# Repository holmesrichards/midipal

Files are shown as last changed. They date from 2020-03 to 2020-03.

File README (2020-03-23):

Midipal, the MIDI swiss army knife.

A midi in, a midi out, a small display, an encoder ; 20 awesome features:

* MIDI monitor
* BPM counter
* Keyboard splitter
* Note dispatcher / voice stealing / polyphonic driver
* Channels merger
* Channel filter
* Clock divider
* Clock source, with swing
* CC and NRPN knob
* 8 pots/sensors voltage reader/controller
* Drum pattern generator (including Euclidian patterns)
* Note, velocity and CC randomizer
* Chord memory
* Arpeggiator
* Sequencer
* CC lfo
* Tempo-synchronized note delay (with transposition and decay velocity)
* Slave start/stop synchronizer (à la Mungo Sync)
* Scale processor / harmonizer
* Ear training game

Forked from pichenettes' version and identical except:
- Eagle brd and sch files converted to XML (making possible import into KiCad)

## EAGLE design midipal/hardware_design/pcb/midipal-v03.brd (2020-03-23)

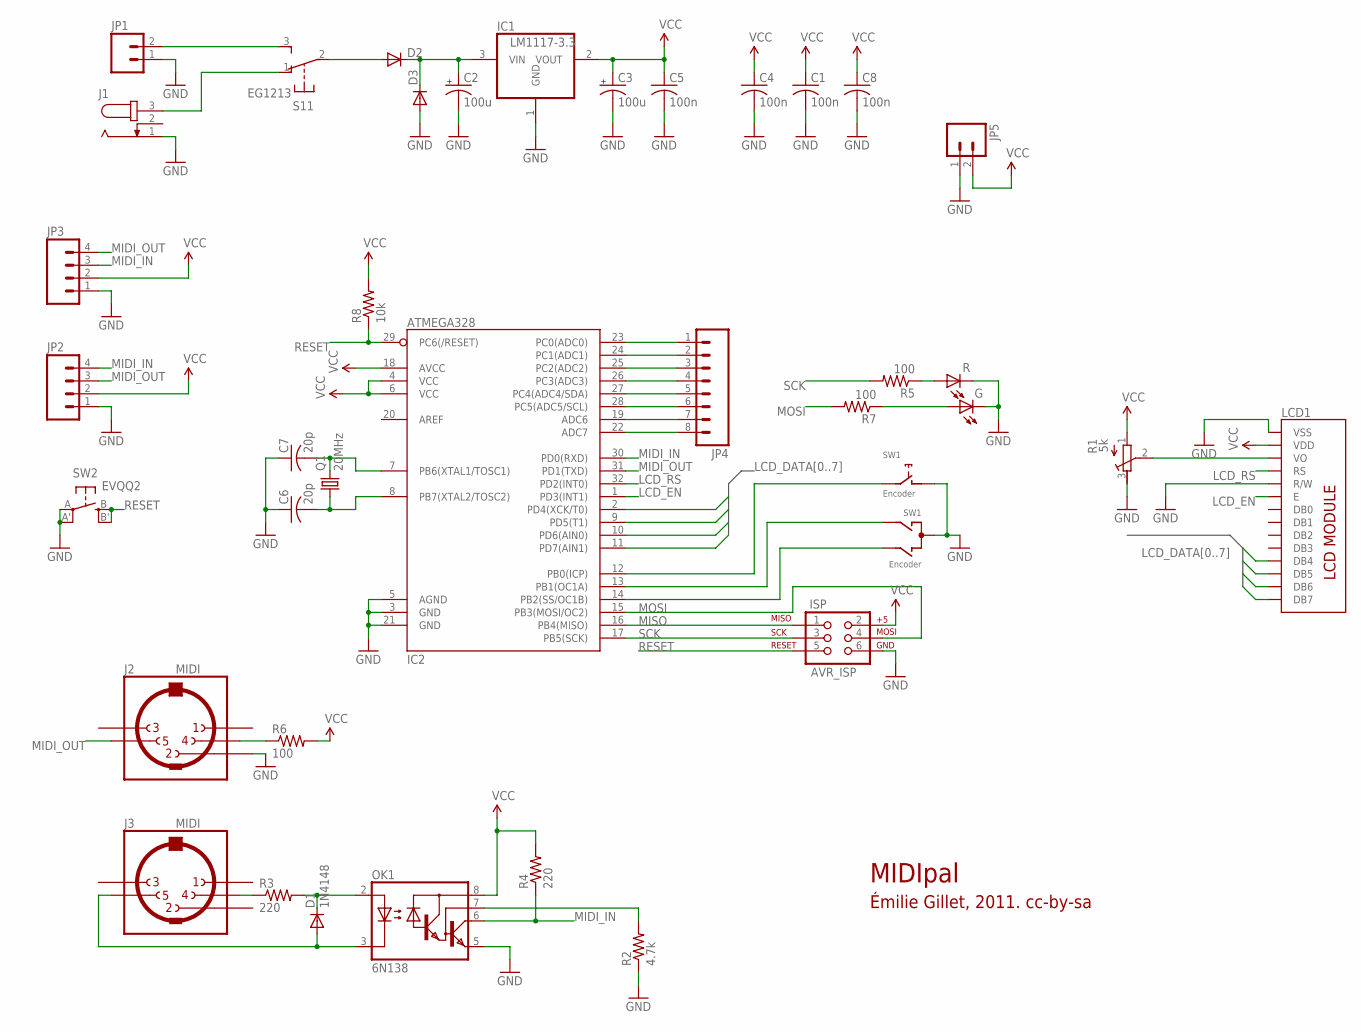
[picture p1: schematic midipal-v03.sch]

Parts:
C1, C4, C5, C8: 100n; C0805
C2, C3: 100u; PANASONIC_D
C6, C7: 20p; C0805
D1: 1N4148; SOD323-W
D2, D3: DIODESMB; SMB-DIODE
G: LEDCHIPLED_1206; CHIPLED_1206
IC1: LM1117-3.3; SOT223
IC2: ATMEGA328; TQFP32-08
ISP: AVR_ISP; 2X3
J1: JACK-PLUG2; SPC4078_BIG_HOLES
J2, J3: MIDI; MAB5SH
JP1: M02; 1X02_LONGPADS
JP2, JP3: M04PTH; 1X04
JP4: M08; 1X08
JP5: M02PTH; 1X02
LCD1: LCD_MODULE_NO_BKL; LCD_MODULE_1X8
OK1: 6N138; DIL8-SMD
Q1: 20MHz; HC49UP
R: LEDCHIPLED_1206; CHIPLED_1206
R1: 5k; RTRIM3296P
R2: 4.7k; M0805
R3: 220; M0805
R4: 220; R0805
R5, R6, R7: 100; R0805
R8: 10k; R0805
S1: EG1213
SW1: Encoder; ALPS_EC12E_SW
SW2: EVQQ2; EVQ-Q2

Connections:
GND: C1.2, C2.-, C3.-, C4.2, C5.2, C6.1, C7.1, C8.2, D3.A, G.C, IC1.1 (GND), IC2.3 (GND), IC2.5 (AGND), IC2.21 (GND), ISP.6, J1.1, J2.2, JP1.1, JP2.1, JP3.1, JP5.1, LCD1.1 (VSS), LCD1.5 (R/W), OK1.5 (GND), R.C, R1.3 (A), R2.1, SW1.C, SW1.D (1), SW2.A, SW2.A' (P1)
LCD_DATA4: IC2.2 (PD4(XCK/T0)), LCD1.11 (DB4)
LCD_DATA5: IC2.9 (PD5(T1)), LCD1.12 (DB5)
LCD_DATA6: IC2.10 (PD6(AIN0)), LCD1.13 (DB6)
LCD_DATA7: IC2.11 (PD7(AIN1)), LCD1.14 (DB7)
LCD_EN: IC2.1 (PD3(INT1)), LCD1.6 (E)
LCD_RS: IC2.32 (PD2(INT0)), LCD1.4 (RS)
MIDI_IN: IC2.30 (PD0(RXD)), JP2.4, JP3.3, OK1.6 (VO), R4.1
MIDI_OUT: IC2.31 (PD1(TXD)), J2.5, JP2.3, JP3.4
MISO: IC2.16 (PB4(MISO)), ISP.1
MOSI: IC2.15 (PB3(MOSI/OC2)), ISP.4, R7.2
unnamed: J1.3, S1.1 (O)
unnamed: C2.+, D2.C, D3.C, IC1.3 (VIN)
unnamed: IC2.23 (PC0(ADC0)), JP4.1
unnamed: D2.A, S1.2
unnamed: IC2.24 (PC1(ADC1)), JP4.2
unnamed: IC2.25 (PC2(ADC2)), JP4.3
unnamed: IC2.26 (PC3(ADC3)), JP4.4
unnamed: IC2.27 (PC4(ADC4/SDA)), JP4.5
unnamed: IC2.28 (PC5(ADC5/SCL)), JP4.6
unnamed: IC2.19 (ADC6), JP4.7
unnamed: IC2.22 (ADC7), JP4.8
unnamed: G.A, R7.1
unnamed: OK1.7 (VB), R2.2
unnamed: R.A, R5.1
unnamed: IC2.14 (PB2(SS/OC1B)), SW1.B
unnamed: IC2.13 (PB1(OC1A)), SW1.A
unnamed: IC2.12 (PB0(ICP)), SW1.E (2)
unnamed: LCD1.3 (VO), R1.2 (S)
unnamed: D1.C, OK1.2 (A), R3.2
unnamed: J2.4, R6.1
unnamed: J3.4, R3.1
unnamed: D1.A, J3.5, OK1.3 (C)
unnamed: C6.2, IC2.8 (PB7(XTAL2/TOSC2)), Q1.1
unnamed: C7.2, IC2.7 (PB6(XTAL1/TOSC1)), Q1.2
RESET: IC2.29 (PC6(/RESET)), ISP.5, R8.1, SW2.B (S), SW2.B' (S1)
SCK: IC2.17 (PB5(SCK)), ISP.3, R5.2
VCC: C1.1, C3.+, C4.1, C5.1, C8.1, IC1.2 (VOUT), IC2.4 (VCC), IC2.6 (VCC), IC2.18 (AVCC), ISP.2, JP2.2, JP3.2, JP5.2, LCD1.2 (VDD), OK1.8 (VCC), R1.1 (E), R4.2, R6.2, R8.2
VIN: JP1.2, S1.3 (S)

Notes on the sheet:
MIDIpal
Émilie Gillet, 2011. cc-by-sa

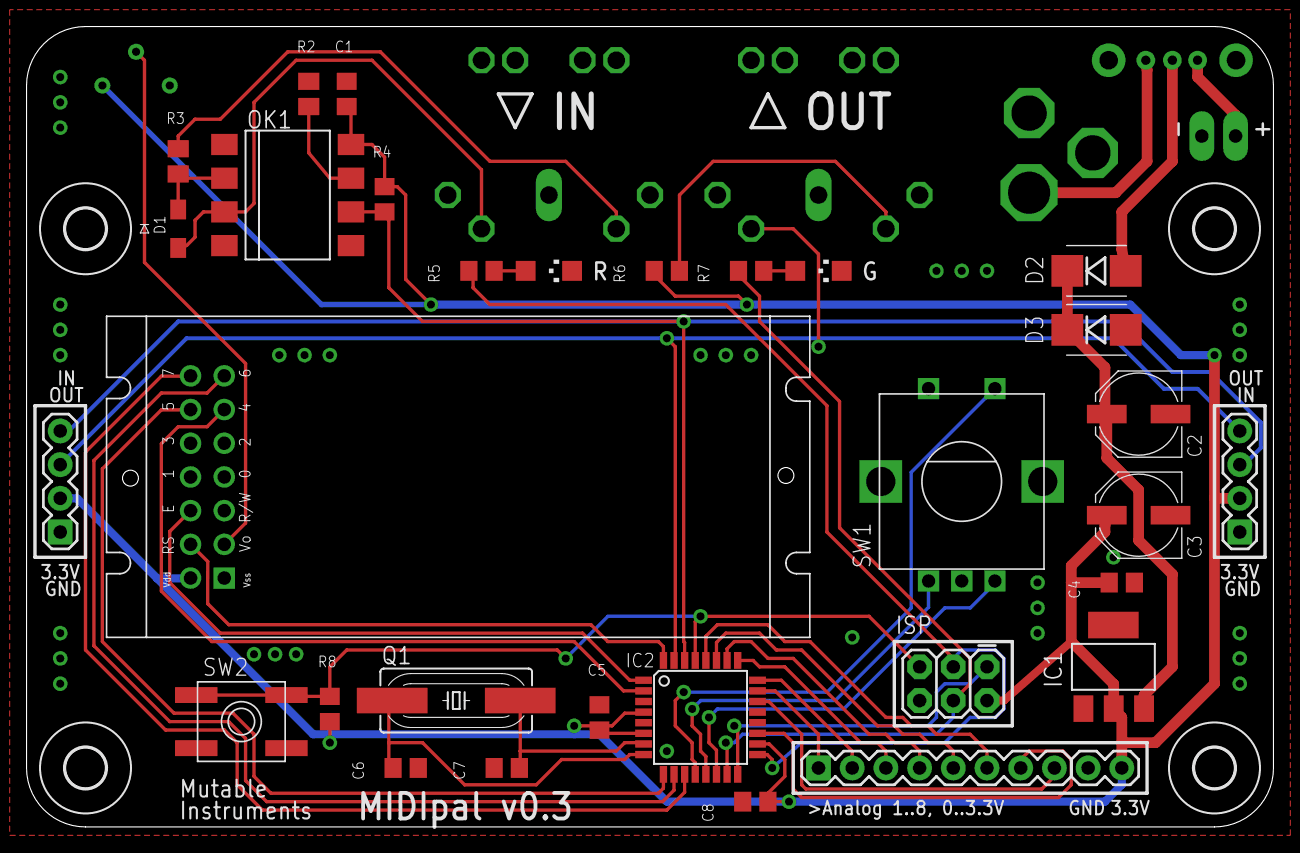
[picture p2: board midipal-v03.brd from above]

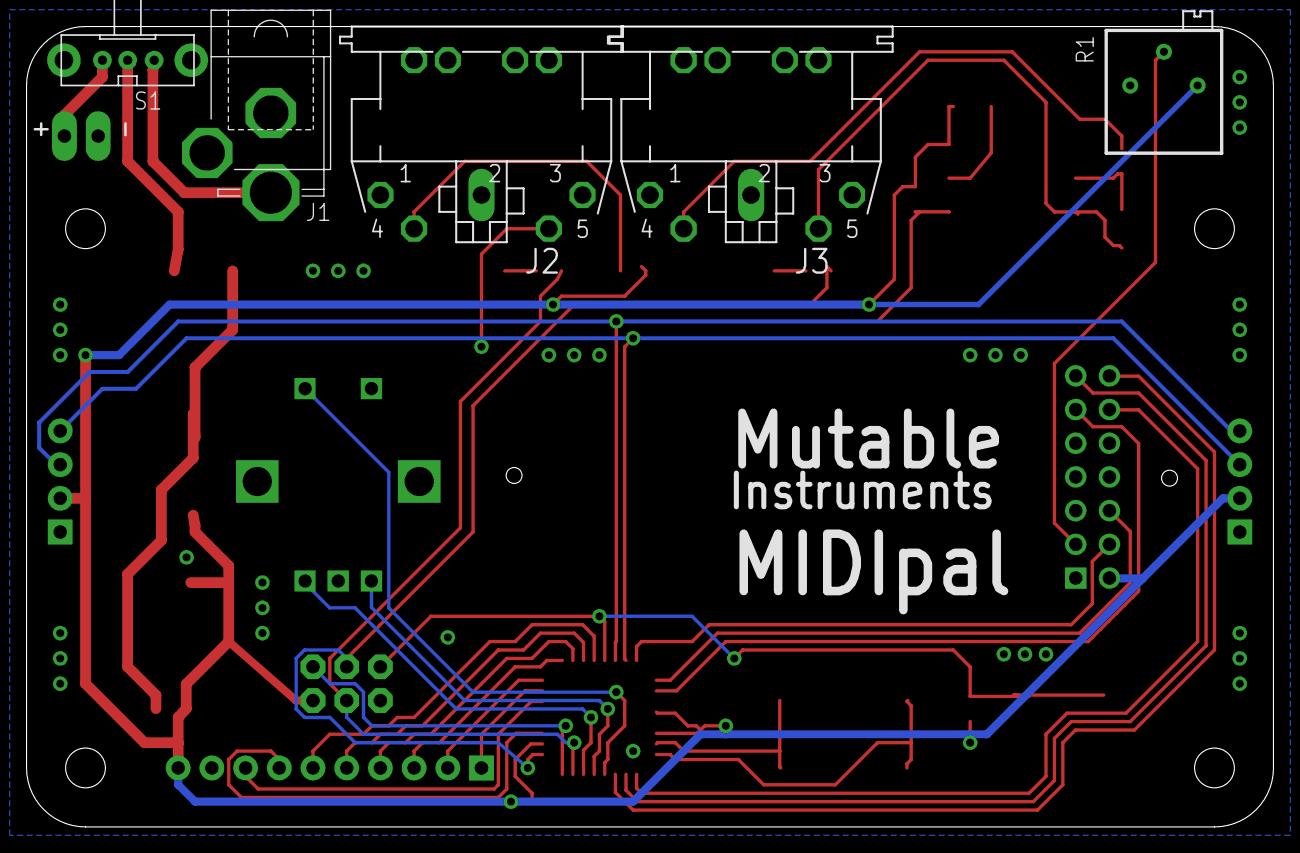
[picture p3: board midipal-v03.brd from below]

Board: 2 copper layers, 94.0 x 60.3 mm, 43 parts (6 on the bottom side), 39 nets.

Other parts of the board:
U$1, U$2, U$4, U$5: 3,0
U$3: SARASWATI
